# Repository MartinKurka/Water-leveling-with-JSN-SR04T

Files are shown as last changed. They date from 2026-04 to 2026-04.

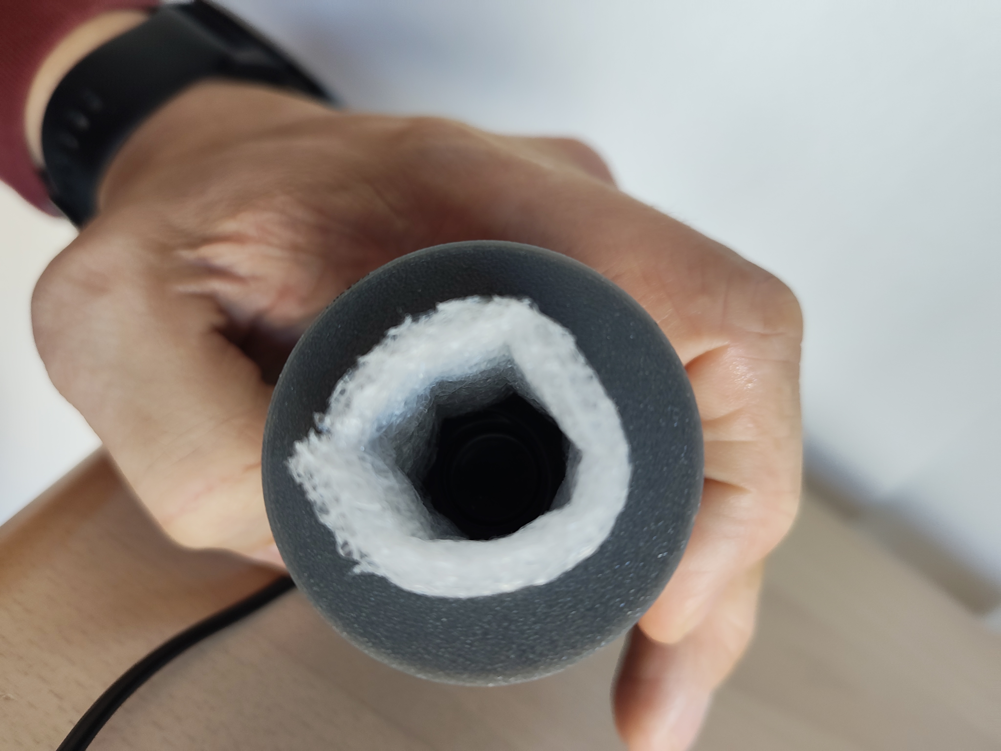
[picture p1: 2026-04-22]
Images/Foam in absorber.jpg

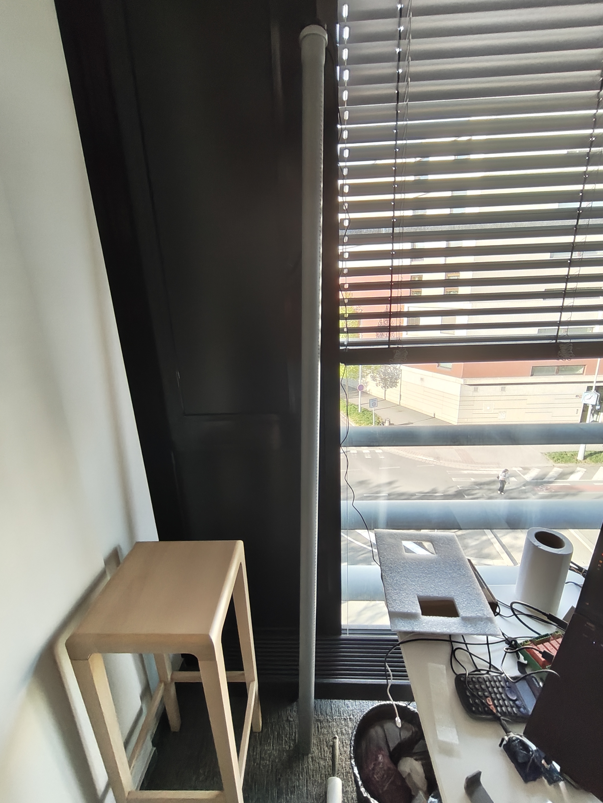
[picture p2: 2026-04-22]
Images/Housing with pipe.jpg

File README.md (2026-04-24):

# Water-leveling-with-JSN-SR04T
ESPHome configuration for measuring water level in a tank using a JSN-SR04T ultrasonic sensor mounted inside a 50mm pipe. Configurable via built-in web server — no reflashing needed.

# 💧 ESPHome Water Level Sensor

ESPHome configuration for ultrasonic water level measurement using **JSN-SR04T** sensor mounted inside a 50mm pipe. Designed for tanks like IBC containers, wells, or any reservoir.

---

## Hardware

| Component | Description |
|---|---|
| ESP8266 D1 Mini Lite | Microcontroller, basically any other ESP |
| JSN-SR04T | Waterproof ultrasonic distance sensor |
| 50mm PVC pipe | Sensor housing (with foam absorber mod) |
| Foam/rubber tubing | Acoustic absorber to narrow beam angle |

### Wiring

| JSN-SR04T | D1 Mini Lite |
|---|---|
| VCC | 5V |
| GND | GND |
| TRIG | GPIO4 |
| ECHO | GPIO5 |

---

## How It Works

The sensor is mounted at the top of a pipe that goes down into the tank. It measures the distance to the water surface. The firmware converts this distance into water height and fill percentage.

```
[Sensor]
    |
    | ← pipe length (cfg)
    |
    |~~~~  ← water surface
    |
    |
   [bottom of tank]
    ↕ max tank level (cfg)
```

**Formula:**
```
water height = pipe length - measured distance + offset
fill % = water height / max tank level × 100
```

---

## The 50mm Pipe Problem & Solution

JSN-SR04T has a ~15° beam angle. Inside a 50mm pipe, the ultrasonic beam reflects off the pipe walls and causes false readings.

**Solution: printed holder with foam absorber**

A 3D printed holder centers the sensor inside the pipe. Foam is placed only around the sensor itself inside the holder — it absorbs the side lobes of the beam right at the source. The pipe itself remains empty.

> No software changes needed — purely a hardware fix.

---

## User Configuration (via Web Server)

All key parameters are adjustable at runtime through the built-in web server — no reflashing needed.

| Setting | Unit | Default | Description |
|---|---|---|---|
| Pipe length | cm | 200 | Physical distance from sensor to tank bottom |
| Max tank level | cm | 80 | Maximum water height in the tank |
| Offset | cm | 0 | Fine-tuning correction (+ or −) |
| Low level threshold | % | 20 | Trigger level for low water warning |

Values are stored in flash memory and survive power cycles.

---

## Sensors & Entities

| Entity | Type | Description |
|---|---|---|
| Water level - distance | Sensor (m) | Raw distance from sensor to water surface |
| Water level - height | Sensor (cm) | Calculated water height from tank bottom |
| Tank percentage | Sensor (%) | Fill level as percentage |
| Low water level | Binary sensor | `ON` when fill % drops below threshold |

---

## Installation

1. Copy `tankwaterlevel.yaml` to your ESPHome config directory
2. Add credentials to `secrets.yaml`:
```yaml
wifi_ssid_1: "your_ssid"
wifi_pass_1: "your_password"
wifi_ssid_2: "your_ssid_2"
wifi_pass_2: "your_password_2"
wifi_ssid_3: "your_ssid_3"
wifi_pass_3: "your_password_3"
wifi_ssid_4: "your_ssid_4"
wifi_pass_4: "your_password_4"
```
3. Flash the device:
```bash
esphome run tankwaterlevel.yaml
```
4. Open the web server at `http://tankwaterlevel.local` and set your parameters

---

## Calibration

1. Set **Pipe length** to the actual distance in cm from the sensor face to the tank bottom
2. Set **Max tank level** to the maximum possible water height in cm
3. If the reading is off, adjust **Offset** (e.g. `-3` if it reads 3 cm too high)
4. Set **Low level threshold** to the % at which you want to be alerted

---

## Notes
- **The pipe must be seamless, with no joints.**
- At the top, where the sensor is located, you need to drill a few small holes to prevent unwanted pressure buildup when the water moves up and down in the pipe.
- Cut a groove in the bottom of the pipe to allow water to enter if the pipe will rest on the bottom of the tank.
- Blind zone: JSN-SR04T cannot reliably measure distances below ~22 cm. If the tank is nearly full and the water surface is within 22 cm of the sensor, readings may be unreliable.
- The median filter (window size 5) smooths out reflections from water surface ripples. This introduces a ~10s delay in readings.
- `include_internal: true` is required in `web_server` for the settings input boxes to appear.

---

## Requirements

- [ESPHome](https://esphome.io) 2024.x or newer
- Home Assistant (optional — works standalone via web server)

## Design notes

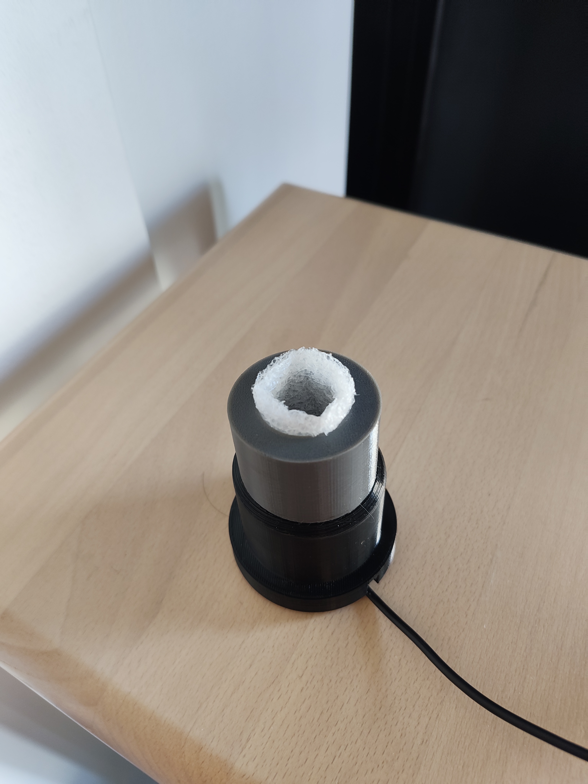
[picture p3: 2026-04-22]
Images/Assebled sensor housing 2.jpg

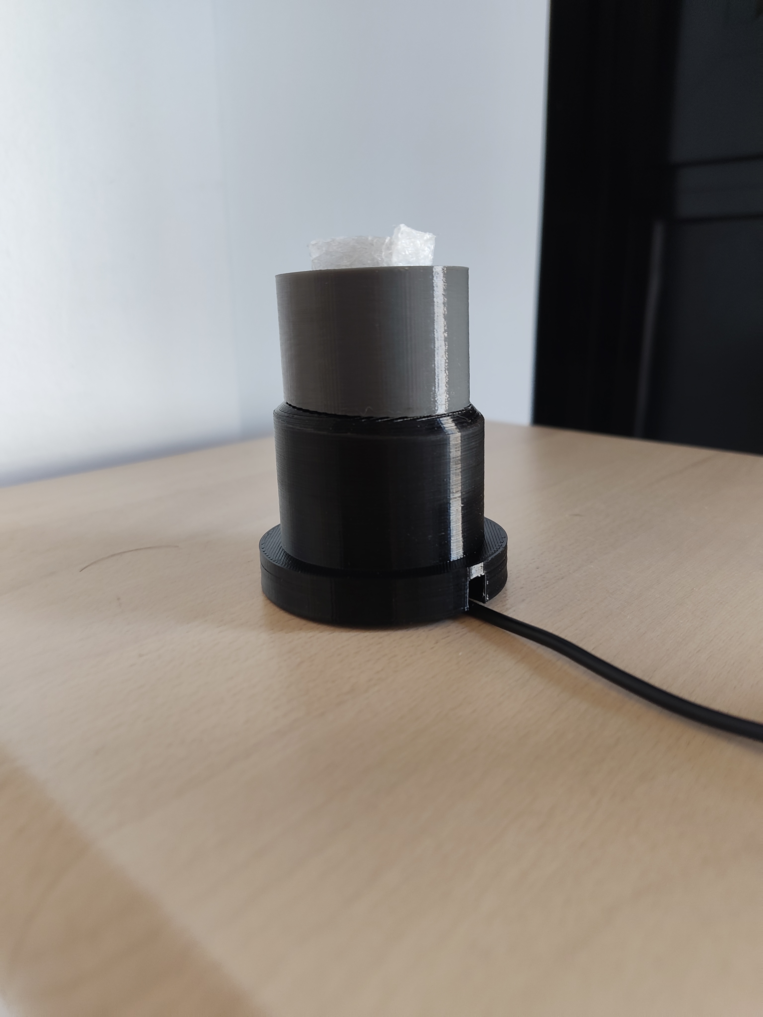
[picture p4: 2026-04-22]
Images/Assebled sensor housing 1.jpg

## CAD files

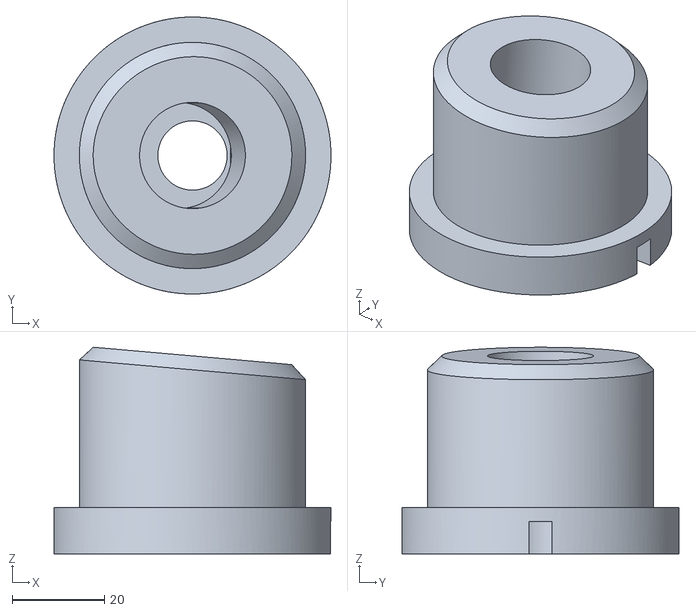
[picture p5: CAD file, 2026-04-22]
3D models/Ultrasonic holder 5 degree slope-Body.stl
60.0 x 60.0 x 44.7

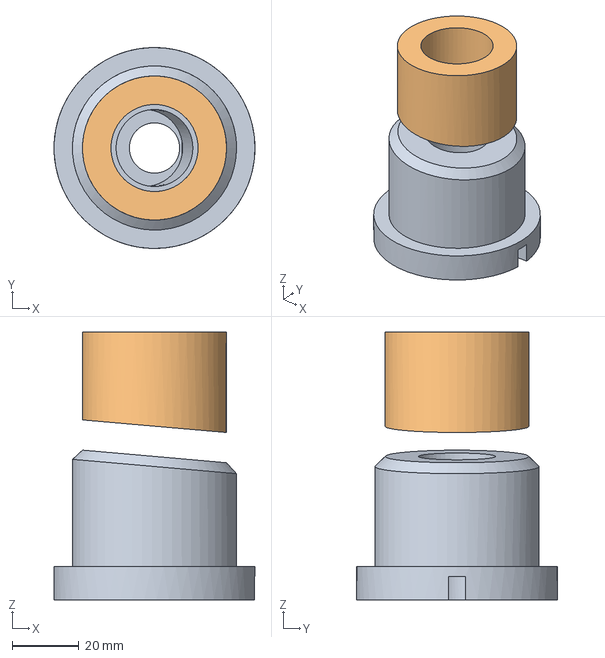
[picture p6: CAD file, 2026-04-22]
3D models/Ultrasonic holder 5 degree slope.FCStd
60.0 x 60.0 x 80.0 mm

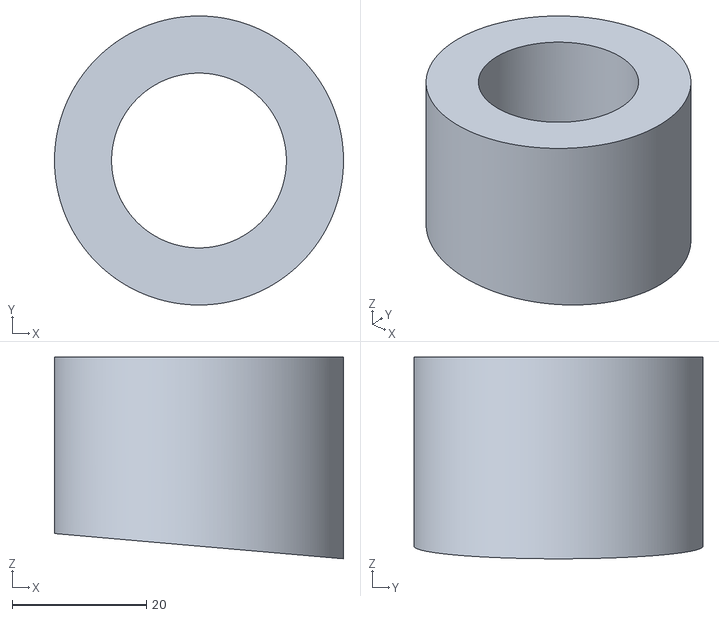
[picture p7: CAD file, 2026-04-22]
3D models/Ultrasonic holder 5 degree slope-Body001.stl
43.0 x 43.0 x 30.0

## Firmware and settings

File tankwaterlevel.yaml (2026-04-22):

esphome:
  name: tankwaterlevel

substitutions:
  pin_trig: GPIO4
  pin_echo: GPIO5

web_server:
  port: 80
  include_internal: true

esp8266:
  board: d1_mini_lite
  framework:
    version: recommended

logger:
  level: DEBUG

wifi:
  networks:
    - ssid: !secret wifi_ssid_1
      password: !secret wifi_pass_1
    - ssid: !secret wifi_ssid_2
      password: !secret wifi_pass_2
    - ssid: !secret wifi_ssid_3
      password: !secret wifi_pass_3
      priority: 10
    - ssid: !secret wifi_ssid_4
      password: !secret wifi_pass_4
      priority: 10
  min_auth_mode: WPA2
  ap:
    ssid: "tankwaterlevel"
    password: "tankwaterlevel"

ota:
  - platform: esphome
    password: ""

captive_portal:

# ---- User configuration ----
number:
  - platform: template
    name: "Settings - Pipe length"
    id: cfg_pipe_length
    unit_of_measurement: "cm"
    min_value: 30
    max_value: 300
    step: 1
    initial_value: 100
    restore_value: true
    optimistic: true
    mode: box

  - platform: template
    name: "Settings - Max tank level"
    id: cfg_max_level
    unit_of_measurement: "cm"
    min_value: 10
    max_value: 300
    step: 1
    initial_value: 80
    restore_value: true
    optimistic: true
    mode: box

  - platform: template
    name: "Settings - Offset"
    id: cfg_offset
    unit_of_measurement: "cm"
    min_value: -20
    max_value: 20
    step: 0.5
    initial_value: 0
    restore_value: true
    optimistic: true
    mode: box

  - platform: template
    name: "Settings - Low level threshold"
    id: cfg_low_level
    unit_of_measurement: "%"
    min_value: 0
    max_value: 100
    step: 1
    initial_value: 20
    restore_value: true
    optimistic: true
    mode: box

# ---- Sensors ----
sensor:
  - platform: ultrasonic
    trigger_pin: ${pin_trig}
    echo_pin: ${pin_echo}
    name: "Water level - distance"
    id: distance_m
    update_interval: 2s
    timeout: 3m
    pulse_time: 10us
    filters:
      - filter_out: nan
      - filter_out: 0.0
      - median:
          window_size: 5
          send_every: 5
          send_first_at: 1
      - clamp:
          min_value: 0.22
          max_value: 2.00
          ignore_out_of_range: true

  - platform: template
    name: "Water level - height"
    id: water_height
    unit_of_measurement: "cm"
    accuracy_decimals: 1
    update_interval: 10s
    lambda: |-
      float dist = id(distance_m).state * 100.0;  // meters → cm
      if (isnan(dist) || dist <= 0) return NAN;
      float height = (id(cfg_pipe_length).state - dist) + id(cfg_offset).state;
      if (height < 0.0) return 0.0;
      if (height > id(cfg_max_level).state) return id(cfg_max_level).state;
      return height;

  - platform: template
    name: "Tank percentage"
    id: tank_percentage
    unit_of_measurement: "%"
    accuracy_decimals: 0
    update_interval: 10s
    lambda: |-
      float v = id(water_height).state;
      if (isnan(v)) return NAN;
      return (v / id(cfg_max_level).state) * 100.0;

binary_sensor:
  - platform: template
    name: "Low water level"
    device_class: problem
    lambda: |-
      float p = id(tank_percentage).state;
      if (isnan(p)) return false;
      return p < id(cfg_low_level).state;

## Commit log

2026-04-22 Enhance README with installation and calibration details
    Expanded README with detailed hardware, wiring, and configuration instructions for the ESPHome water level sensor project.
2026-04-22 Update default pipe length to 200 cm
2026-04-22 added models and Images/Assebled sensor housing 1.jpg
    JIRA:noissue
    [Ultrasonic holder 5 degree slope-Body.stl, Ultrasonic holder 5 degree slope-Body001.stl, Ultrasonic holder 5 degree slope.FCStd]
2026-04-24 Update README with pipe installation notes
    Added important notes regarding pipe installation and sensor limitations.
